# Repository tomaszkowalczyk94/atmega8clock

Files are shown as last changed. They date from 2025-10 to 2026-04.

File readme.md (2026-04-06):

# ATmega8 Digital LED Clock ⏰

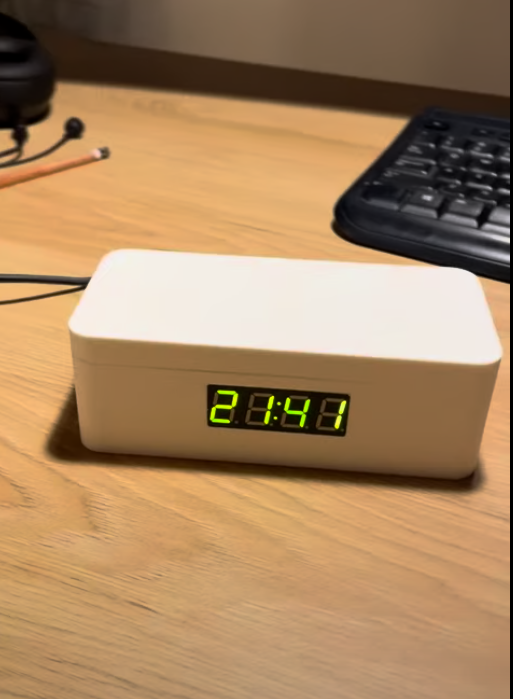
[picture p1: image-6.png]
|  |

A custom-built, DIY digital clock powered by an **ATmega8** microcontroller and a 4-digit 7-segment green LED display. This project involves a custom perfboard circuit, transistor-based display multiplexing, and a fully custom 3D-printed enclosure designed in FreeCAD.

## 🌟 Features
* **Microcontroller:** Atmel ATmega8 
* **Display:** 0.56" 4-Digit 7-Segment LED display with colons/dots (LED4-AF-05643FG-B PBF).
* **Multiplexing:** Utilizes BC547 NPN transistors for switching the common anodes.
* **Custom Enclosure:** 3D printed case and lid, originally modeled in FreeCAD.
* **Programming:** Flashed via a USBAsp programmer using Arduino IDE.

---

## 🛠️ Hardware & Components

* **1x ATmega8** Microcontroller
* **1x LED4-AF-05643FG-B PBF** (4-Digit 7-Segment Display, 0.56", Green, Common Anode)
* **5x BC547 NPN Transistors** (Used to drive the common anodes)
* **Resistors** (For base current limiting on the transistors and segment current limiting)
* **USBAsp Programmer** (For flashing the ATmega8)
* Universal perfboard/stripboard

---

## 🔌 Circuit & Pinout

The display requires multiplexing. The **Common Anodes** are driven by the ATmega8 via BC547 NPN transistors (which conduct when a high signal is applied to the base). The **Cathodes** are connected directly to the ATmega8 digital pins. 

### Anode Connections (via BC547 Transistors)
| Display Pin | ATmega8 Pin (Arduino IDE) | Function |
| :--- | :--- | :--- |
| **14** | Digital Pin 13 | DIGIT 1 |
| **11** | Digital Pin 10 | DIGIT 2 |
| **10** | Digital Pin 9 | DIGIT 3 |
| **7** | Digital Pin 6 | Colon / Dots (UC, LC) |
| **6** | Digital Pin 5 | DIGIT 4 |

### Cathode Connections (Direct to ATmega8)
| Display Pin | ATmega8 Pin (Arduino IDE) | Segment |
| :--- | :--- | :--- |
| **13** | Digital Pin 12 | Segment A |
| **9** | Digital Pin 8 | Segment B |
| **4** | Digital Pin 3 | Segment C |
| **2** | Digital Pin 1 | Segment D |
| **1** | Digital Pin 0 | Segment E |
| **12** | Digital Pin 11 | Segment F |
| **5** | Digital Pin 4 | Segment G |
| **3** | Digital Pin 2 | Dot (DP / OP) |
| **8** | Digital Pin 7 | Colon (UC, LC) |

---

## 📦 3D Printed Enclosure

The repository includes custom 3D models for the clock's housing.
* **`case.FCStd`**: The original FreeCAD project file. Use this if you want to modify the dimensions or design.
* **`case-PartBody.stl`**: The main body of the enclosure, ready for slicing and 3D printing.
* **`case-wieczkoThickness001.stl`**: The back lid/cover for the enclosure.

*Tip: Print with standard PLA/PETG. No special supports are required if oriented face-down.*

---

## 💻 Software & Programming

The code for this project was written in the Arduino IDE and leverages basic multiplexing logic to illuminate the 7-segment display. 

**Flashing the ATmega8:**
1. You will need a **USBAsp** programmer.
2. Install the necessary drivers using [Zadig](https://zadig.akeo.ie/).
3. Connect the USBAsp to the ATmega8 via the ISP headers.
4. In Arduino IDE, select the ATmega8 board, set the programmer to "USBAsp", and click **"Upload Using Programmer"**.

*Helpful resources for programming raw AVR chips:*
* [Majsterkowo: Programming microcontrollers with USBAsp (Polish)](https://majsterkowo.pl/programowanie-mikrokontrolerow-za-pomoca-programatora-usbasp/)
* [YouTube Tutorial](https://www.youtube.com/watch?v=X01Nhq8TeY0&t=58s)

---

## 📸 Gallery

| Circuit Design | 
| :---: 
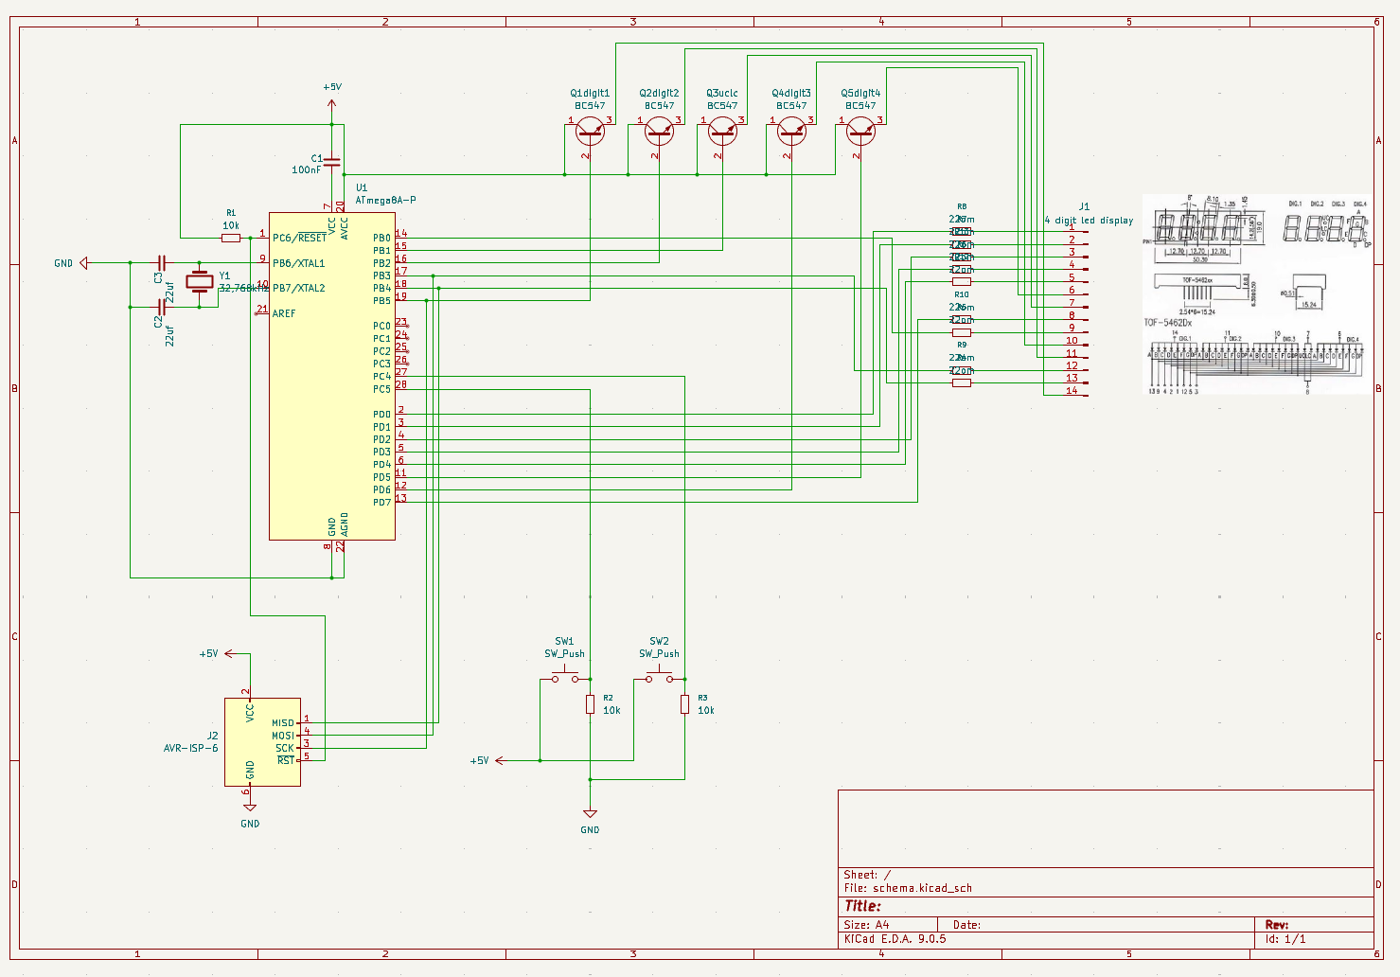
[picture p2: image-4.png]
|  |

| Prototype | 
| :---: 
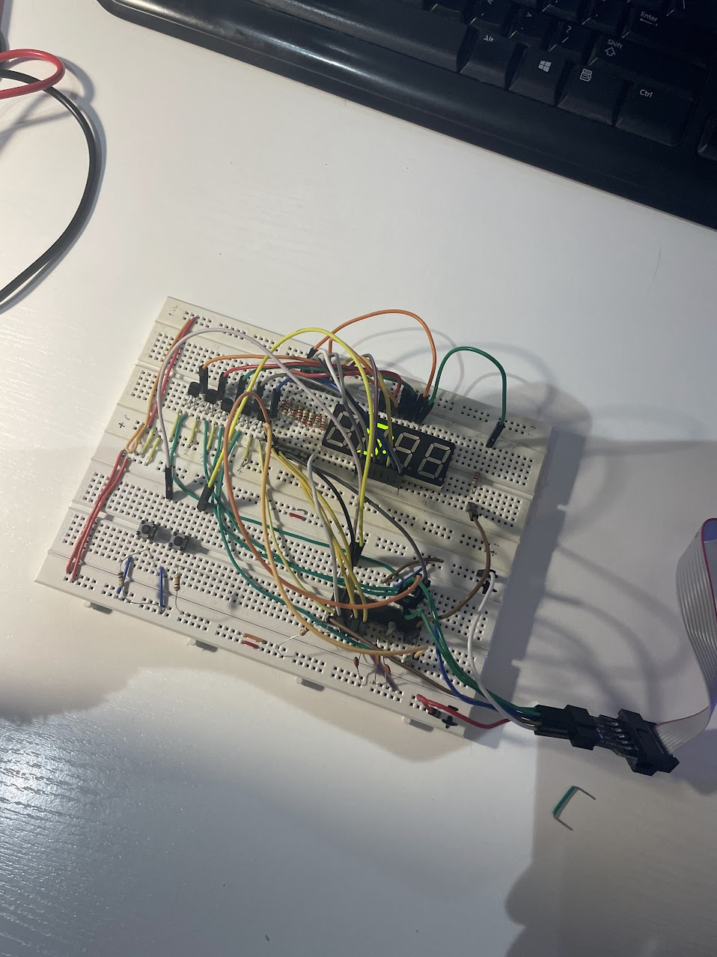
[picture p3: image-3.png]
|  |

| Final electronic board | 
| :---: 
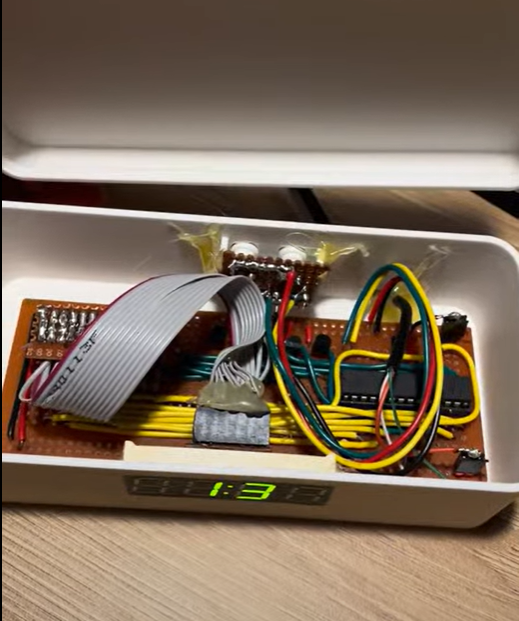
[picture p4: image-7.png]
|  |

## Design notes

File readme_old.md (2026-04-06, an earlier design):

* USBAsp drivers: https://zadig.akeo.ie/
* https://majsterkowo.pl/programowanie-mikrokontrolerow-za-pomoca-programatora-usbasp/
* https://www.youtube.com/watch?v=X01Nhq8TeY0&t=58s
* https://veecad.com/downloads.html







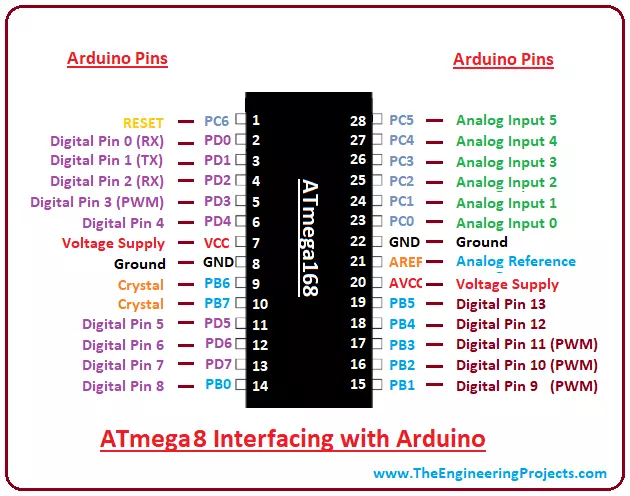
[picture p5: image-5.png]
	
LED4-AF-05643FG-B PBF

Wyświetlacz LED 14,20mm 0,56" cztery cyfry

zielony (570nm) , 4000 ucd (10mA) , wspólna anoda

aktywne wszystkie kropki (przy cyfrach i zegarkowe)

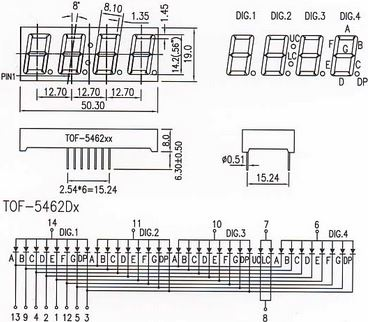
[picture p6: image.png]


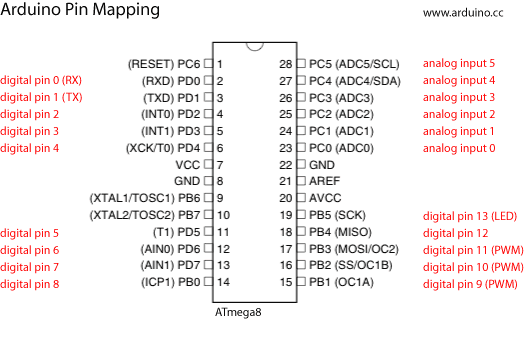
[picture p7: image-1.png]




typ NPN zacznie przewodzić, gdy do bazy przyłożymy napięcie dodatnie względem emitera, czyli przy standardowym podłączeniu na bazę podamy wysoki potencjał (plus z baterii),
typ PNP zacznie przewodzić, gdy do bazy przyłożymy napięcie ujemne względem emitera, czyli przy standardowym podłączeniu na bazę podamy niski potencjał (masę, minus z baterii).

bc547 b (NPN)
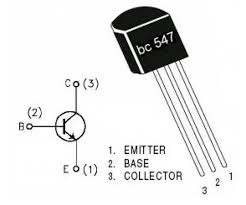
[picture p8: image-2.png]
 

 połączenie do atmega8:
 nr pinu wyświetlacza odpowiada pinowi cyfrowemu arduino

Podłączenie anod (+) przez bc547
 displey - atmega
14 - digital pin 13 (DIGIT 1)
11 - digital pin 10 (DIGIT 2)
10 - digital pin 9 (DIGIT 3)
7 - digital pin 6 (UC, LC)
6 - digital pin 5 (DIGIT 4)

podłączenie katod (-) bezpośrednio do atmegi
13 - digital pin 12 (segment A)
9 - digital pin 8 (segment B)
4 - digital pin 3 (segment C)
2 - digital pin 1 (segment D)
1 - digital pin 0 (segment E)
12 - digital pin 11 (segment F)
5 - digital pin 4 (segment G)
3 - digital pin 2 (segment OP)
8 - digital pin 7 (segment UC, LC)

## chatgpt prompt:

napisz mi kod do arduino studio. Posiadam atmega 8 i wyświetlacz 4 segmentowy z kropkami przy cyfrach i dwukropkiem między drugą i trzecią cyfrą. 

Chce zrobić zegarek z wyświetlaczem 7 segmentowym. Oto podłączenie pinów:

 połączenie do atmega8:
 nr pinu wyświetlacza odpowiada pinowi cyfrowemu arduino

Podłączenie anod (-) przez bc547
 displey - atmega
14 - digital pin 13 (DIGIT 1)
11 - digital pin 10 (DIGIT 2)
10 - digital pin 9 (DIGIT 3)
7 - digital pin 6 (UC, LC)
6 - digital pin 5 (DIGIT 4)

podłączenie katod (-) bezpośrednio do atmegi
13 - digital pin 12 (segment A)
9 - digital pin 8 (segment B)
4 - digital pin 3 (segment C)
2 - digital pin 1 (segment D)
1 - digital pin 0 (segment E)
12 - digital pin 11 (segment F)
5 - digital pin 4 (segment G)
3 - digital pin 2 (segment OP)
8 - digital pin 7 (segment UC, LC)

każda cyfra ma wspólną anode, i różne katody.

Stan niski na katodzie włącza wyświetlanie

Chce aby co sekunde migał dwukropem między cyfrą 3 a 2. Są to piny nazwane UC i LC. (anoda ditial pin 6 na atmega, katoda digital pin 7 na atmega)
Komentarze mają być po angielsku

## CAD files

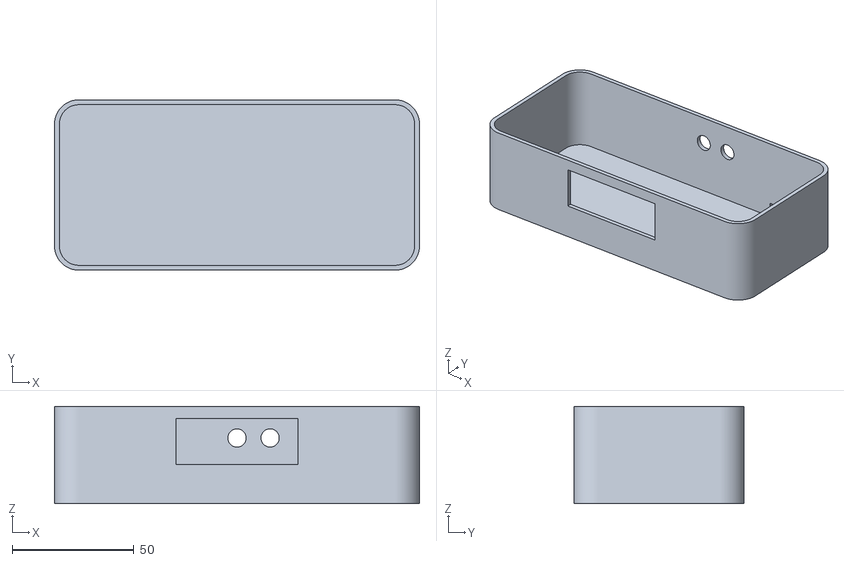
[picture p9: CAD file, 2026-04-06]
case-PartBody.stl
150.0 x 70.0 x 40.0

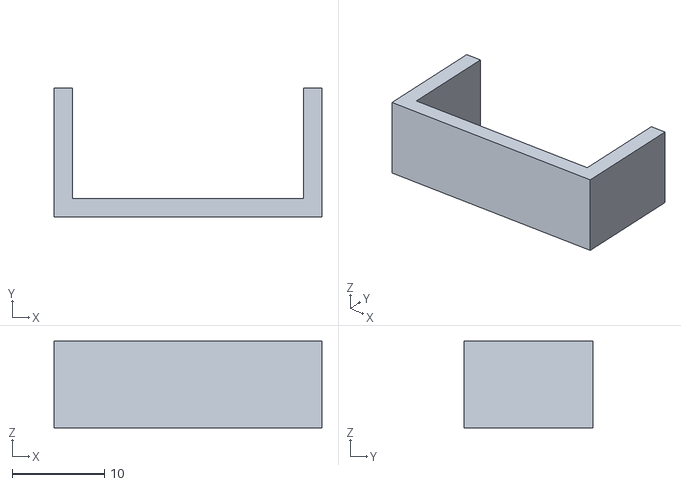
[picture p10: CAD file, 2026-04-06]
button holder.stl
29.0 x 14.0 x 9.39

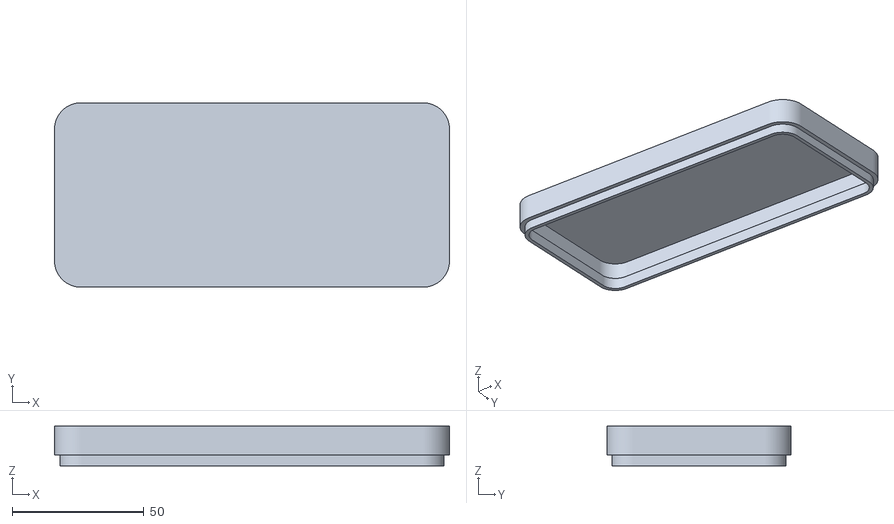
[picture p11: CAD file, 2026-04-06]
case-wieczkoThickness001.stl
150.0 x 70.0 x 15.0

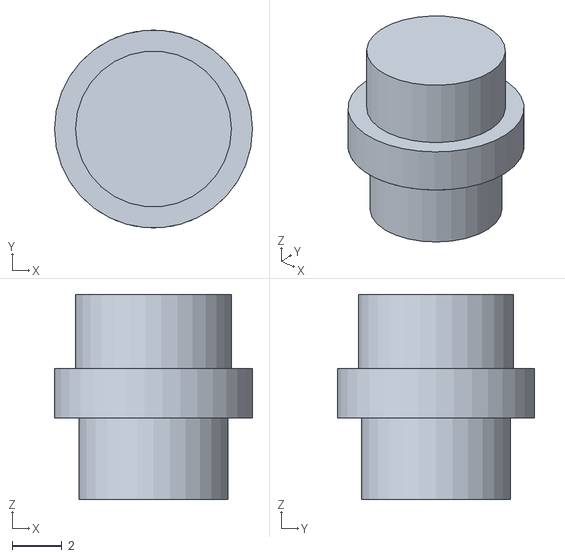
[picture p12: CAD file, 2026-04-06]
button.stl
8.00 x 8.00 x 8.30

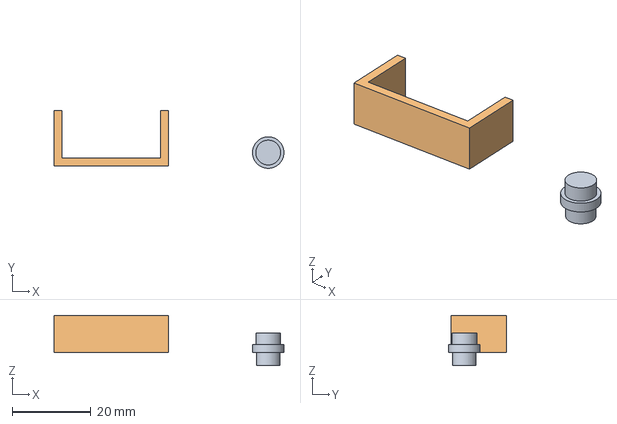
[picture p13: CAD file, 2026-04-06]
case.FCStd
58.3 x 14.6 x 12.7 mm
buttons

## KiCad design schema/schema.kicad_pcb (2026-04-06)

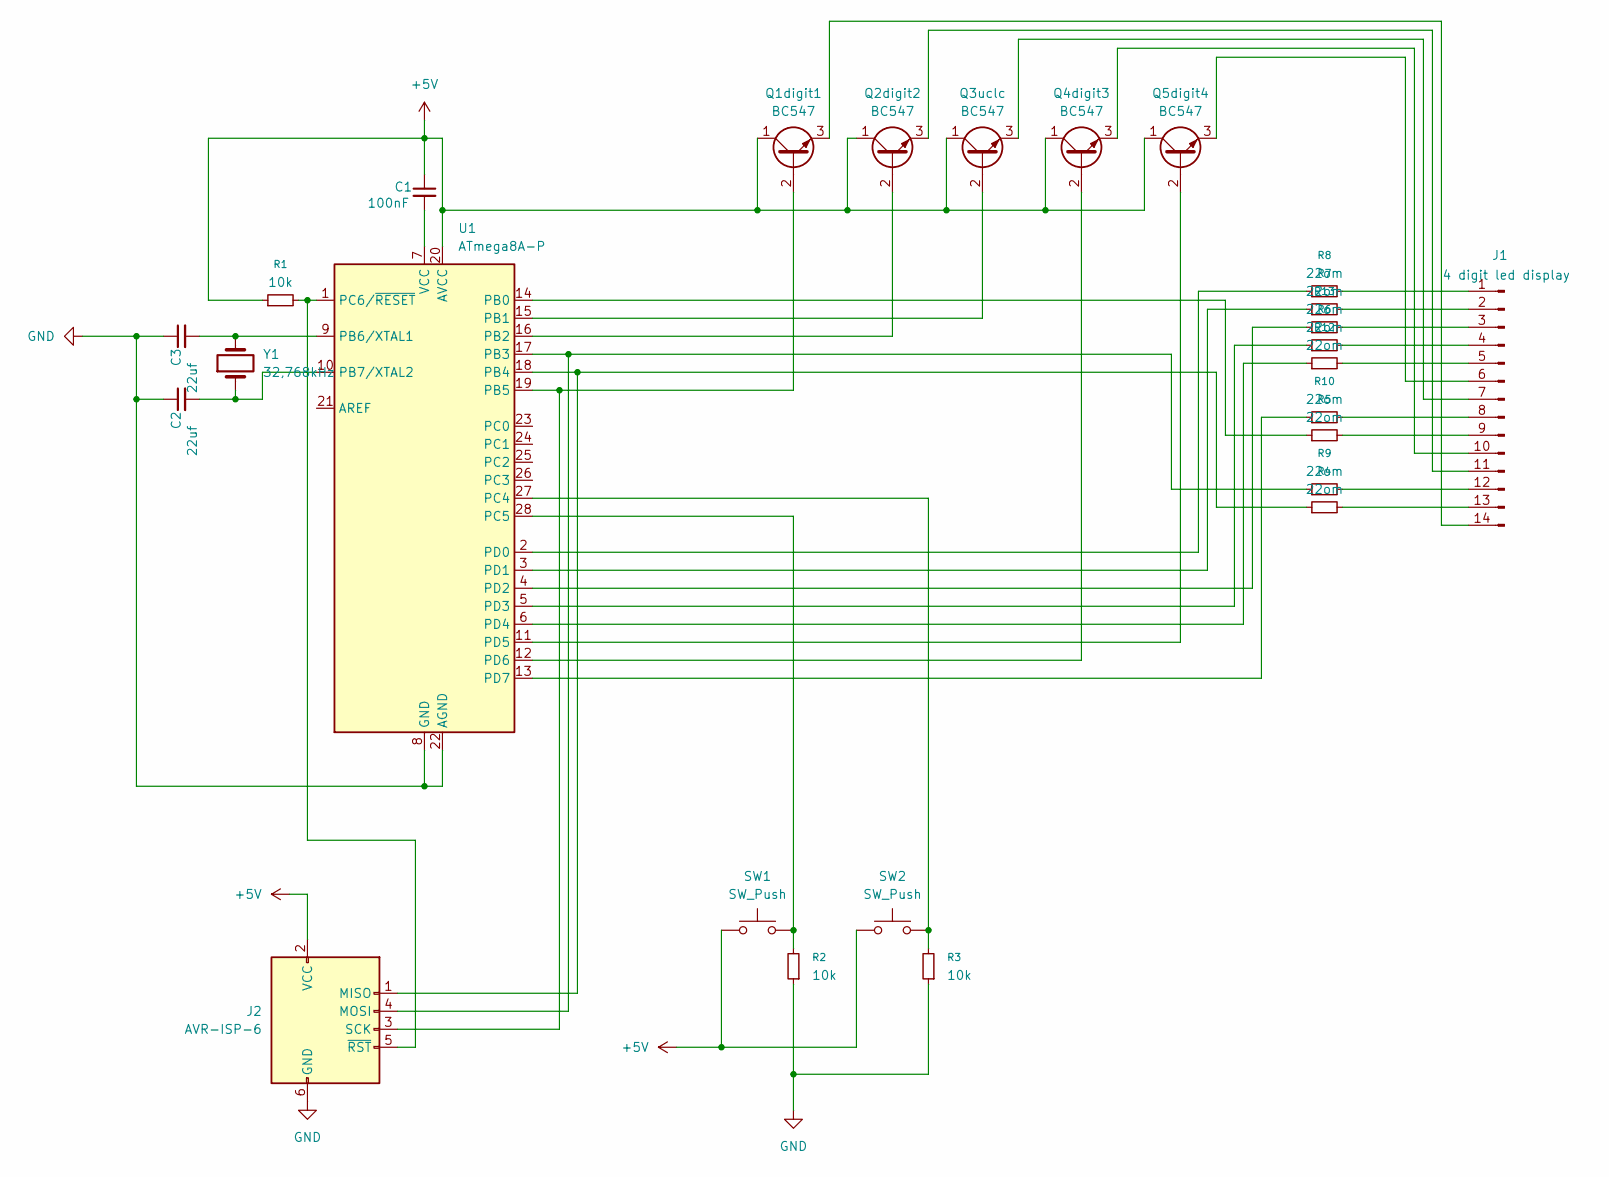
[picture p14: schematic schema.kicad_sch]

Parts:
C1: 100nF
C2, C3: 22uf
J1: 4 digit led display; Hirose_DF13-14P-1.25DSA_1x14_P1.25mm_Vertical
J2: AVR-ISP-6
Q1digit1, Q2digit2, Q3uclc, Q4digit3, Q5digit4: BC547; TO-92_Inline
R1, R2, R3: 10k
R4, R5, R6, R7, R8, R9, R10, R12, R13: 22om
SW1, SW2: SW_Push
U1: ATmega8A-P; DIP-28_W7.62mm
Y1: 32,768kHz

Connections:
+5V: C1.1, J2.2 (VCC), Q1digit1.1 (C), Q2digit2.1 (C), Q3uclc.1 (C), Q4digit3.1 (C), Q5digit4.1 (C), R1.1, SW1.1, SW2.1, U1.20 (AVCC); also elsewhere on the board
GND: C2.1, C3.1, J2.6 (GND), R2.1, R3.1, U1.8 (GND), U1.22 (AGND)
unnamed: J1.1, R8.2
unnamed: J1.2, R7.2
unnamed: J1.3, R13.2
unnamed: J1.4, R6.2
unnamed: J1.5, R12.2
unnamed: J1.6, Q5digit4.3 (E)
unnamed 8: J1.7, Q3uclc.3 (E); also elsewhere on the board
unnamed: J1.8, R10.2
unnamed: J1.9, R5.2
unnamed: J1.10, Q4digit3.3 (E)
unnamed: J1.11, Q2digit2.3 (E)
unnamed: J1.12, R9.2
unnamed: J1.13, R4.2
unnamed: J1.14, Q1digit1.3 (E)
unnamed: J2.1 (MISO), R4.1, U1.18 (PB4)
unnamed: J2.4 (MOSI), R9.1, U1.17 (PB3)
unnamed: J2.3 (SCK), Q1digit1.2 (B), U1.19 (PB5)
unnamed: J2.5 (~RST), R1.2, U1.1 (PC6/~RESET)
unnamed: Q2digit2.2 (B), U1.16 (PB2)
unnamed 21: Q3uclc.2 (B), U1.15 (PB1); also elsewhere on the board
unnamed: Q4digit3.2 (B), U1.12 (PD6)
unnamed: Q5digit4.2 (B), U1.11 (PD5)
unnamed: R5.1, U1.14 (PB0)
unnamed: C3.2, U1.9 (PB6/XTAL1), Y1.2
unnamed: C2.2, U1.10 (PB7/XTAL2), Y1.1
unnamed: R3.2, SW2.2, U1.27 (PC4)
unnamed: R2.2, SW1.2, U1.28 (PC5)
unnamed: R8.1, U1.2 (PD0)
unnamed: R7.1, U1.3 (PD1)
unnamed: R13.1, U1.4 (PD2)
unnamed: R6.1, U1.5 (PD3)
unnamed: R12.1, U1.6 (PD4)
unnamed: R10.1, U1.13 (PD7)
unnamed: C1.2, U1.7 (VCC)

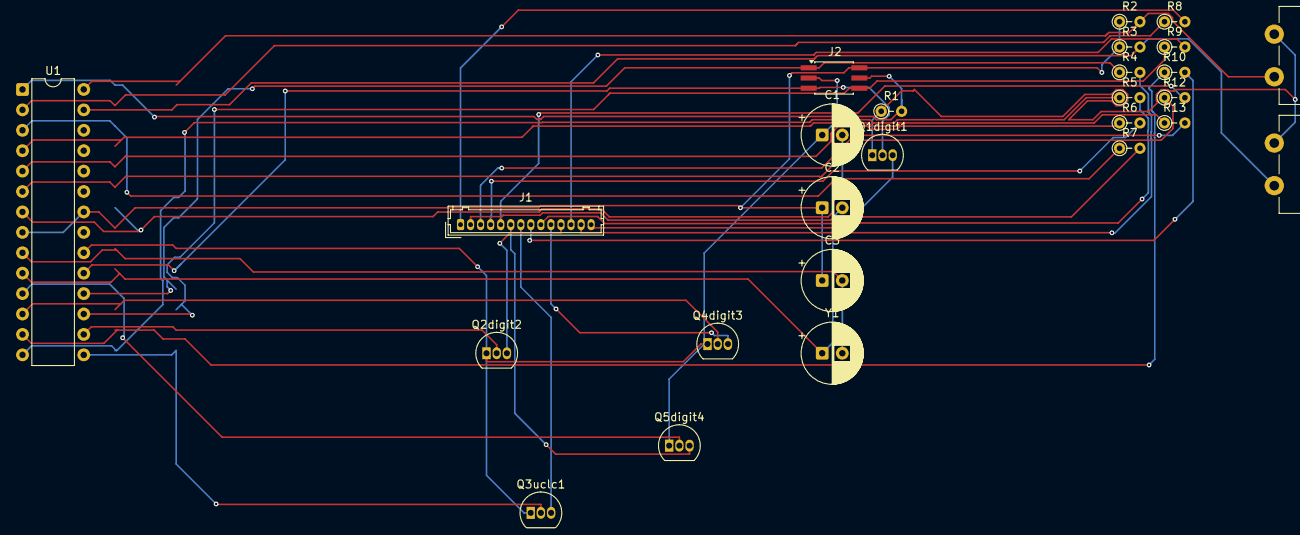
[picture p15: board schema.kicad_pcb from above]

Board: 2 copper layers, 26 parts (0 on the bottom side), 36 nets.

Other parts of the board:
Q3uclc1: BC547; TO-92_Inline

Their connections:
+5V: Q3uclc1.1 (C); also elsewhere on the board
unnamed 8: Q3uclc1.3 (E); also elsewhere on the board
unnamed 21: Q3uclc1.2 (B); also elsewhere on the board

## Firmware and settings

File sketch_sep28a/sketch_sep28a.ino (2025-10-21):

/*
  4-digit 7-segment clock for ATmega8
  Common anode display controlled through BC547 transistors
  Active LOW segments (LOW = ON)
  Active HIGH digit select (HIGH = digit ON)
  Colon (:) blinks every second between digit 2 and digit 3
  Comments in English
*/

#include <Arduino.h>

const int button1 = A5;   // pin przycisku
const int button2 = A4;
const unsigned long debounceDelay = 50; // czas antydrganiowy (ms)

int button1State;             // aktualny stan
int button2State;   
int lastButton1State = LOW;   // poprzedni stan
int lastButton2State = LOW;   
unsigned long lastDebounceTime1 = 0; // ostatni czas zmiany
unsigned long lastDebounceTime2 = 0; // ostatni czas zmiany

const int delayBetweenDigits = 2; 

// ----- Segment pin definitions -----
const int segA = 12; // segment A
const int segB = 8;  // segment B
const int segC = 3;  // segment C
const int segD = 1;  // segment D
const int segE = 0;  // segment E
const int segF = 11; // segment F
const int segG = 4;  // segment G
const int segDP = 2; // decimal point
const int segUC = 7; // colon cathode (UC/LC)

// ----- Digit control pins (through BC547 transistors) -----
const int digit1 = 13; // DIGIT 1
const int digit2 = 10; // DIGIT 2
const int digit3 = 9;  // DIGIT 3
const int digitUC_LC = 6; // Colon anode
const int digit4 = 5;  // DIGIT 4

// ----- Time variables -----
int hours = 0;
int minutes = 0;
int seconds = 0;

unsigned long previousMillis = 0;
bool colonState = true; // Blinking colon state
bool dotDigit1 = false;
bool dotDigit2 = false;
bool dotDigit3 = false;
bool dotDigit4 = false;

// ----- Segment patterns for digits 0–9 (active LOW) -----
const byte digitPatterns[10][7] = {
  {0,0,0,0,0,0,1}, // 0
  {1,0,0,1,1,1,1}, // 1
  {0,0,1,0,0,1,0}, // 2
  {0,0,0,0,1,1,0}, // 3
  {1,0,0,1,1,0,0}, // 4
  {0,1,0,0,1,0,0}, // 5
  {0,1,0,0,0,0,0}, // 6
  {0,0,0,1,1,1,1}, // 7
  {0,0,0,0,0,0,0}, // 8
  {0,0,0,0,1,0,0}  // 9
};

// ----- Setup -----
void setup() {
  pinMode(button1, INPUT);
  pinMode(button2, INPUT);

  // Segment pins
  pinMode(segA, OUTPUT);
  pinMode(segB, OUTPUT);
  pinMode(segC, OUTPUT);
  pinMode(segD, OUTPUT);
  pinMode(segE, OUTPUT);
  pinMode(segF, OUTPUT);
  pinMode(segG, OUTPUT);
  pinMode(segDP, OUTPUT);
  pinMode(segUC, OUTPUT);

  // Digit pins
  pinMode(digit1, OUTPUT);
  pinMode(digit2, OUTPUT);
  pinMode(digit3, OUTPUT);
  pinMode(digitUC_LC, OUTPUT);
  pinMode(digit4, OUTPUT);

  allDigitsOff();

  timer2_init();
}

// ----- Helper functions -----

// Turn off all digits
void allDigitsOff() {
  digitalWrite(digit1, LOW);
  digitalWrite(digit2, LOW);
  digitalWrite(digit3, LOW);
  digitalWrite(digitUC_LC, LOW);
  digitalWrite(digit4, LOW);
}

// Display a digit (0–9)
void showNumber(int num, bool dot) {
  for (int i = 0; i < 7; i++) {
    digitalWrite(segmentPin(i), digitPatterns[num][i]);
  }
  digitalWrite(segDP, !dot); // Decimal point off
}

// Return correct segment pin by index
int segmentPin(int index) {
  const int pins[7] = {segA, segB, segC, segD, segE, segF, segG};
  return pins[index];
}

// Show one number on a selected digit
void showDigit(int number, bool dot,  int digitPin) {
  allDigitsOff();         // Disable all digits
  showNumber(number, dot);     // Set segments
  digitalWrite(digitPin, HIGH); // Enable digit (active HIGH)
}

// Display the time HH:MM with blinking colon
void displayTime() {
  int d1 = hours / 10;
  int d2 = hours % 10;
  int d3 = minutes / 10;
  int d4 = minutes % 10;
  
  showDigit(d1, dotDigit1, digit1);
  delay(delayBetweenDigits);
  
  showDigit(d2, dotDigit2, digit2);
  delay(delayBetweenDigits);
  

  // Colon blink control
  
  if (colonState) {
    allDigitsOff();
    digitalWrite(segUC, LOW);     // Colon ON (active LOW)
    digitalWrite(digitUC_LC, HIGH);
  } else {
    allDigitsOff();
    digitalWrite(digitUC_LC, LOW);
    digitalWrite(segUC, HIGH);    // Turn colon OFF after brief flash
  }
  delay(delayBetweenDigits);

  showDigit(d3, dotDigit3, digit3);
  delay(delayBetweenDigits);

  showDigit(d4, dotDigit4, digit4);
  delay(delayBetweenDigits);
}


// ----- Time update -----
void updateTime() {
    seconds++;

    // Blink colon every second
    colonState = !colonState;

    if (seconds >= 60) {
      seconds = 0;
      minutes++;
      if (minutes >= 60) {
        minutes = 0;
        hours++;
        if (hours >= 24) hours = 0;
      }
    }
  
}


// ----- Main loop -----
void loop() {


  handleButton1();
  handleButton2();


  displayTime();
  
}



void handleButton1() {
  
  int reading = digitalRead(button1);
  // jeśli stan się zmienił → zresetuj timer
  if (reading != lastButton1State) {
    lastDebounceTime1 = millis();
  }

  // jeśli minął czas stabilizacji
  if ((millis() - lastDebounceTime1) > debounceDelay) {
    // jeśli stan jest inny niż ostatnio potwierdzony
    if (reading != button1State) {
      button1State = reading;

      if (button1State == HIGH) {
        button1Pressed();
      }
    }
  }

  lastButton1State = reading;
}

void handleButton2() {
  
  int reading = digitalRead(button2);
  // jeśli stan się zmienił → zresetuj timer
  if (reading != lastButton2State) {
    lastDebounceTime2 = millis();
  }

  // jeśli minął czas stabilizacji
  if ((millis() - lastDebounceTime2) > debounceDelay) {
    // jeśli stan jest inny niż ostatnio potwierdzony
    if (reading != button2State) {
      button2State = reading;

      if (button2State == HIGH) {
        button2Pressed();
      }
    }
  }

  lastButton2State = reading;
}

void button1Pressed() {
  if(dotDigit2) {
    dotDigit2 = false;
    dotDigit4 = true;
    return;
  }
  if(dotDigit4) {
    dotDigit4 = false;
    return;
  }
  dotDigit2 = true;
}

void button2Pressed() {
  if(dotDigit2) {
    hours++;
    if (hours >= 24) hours = 0;
  }

  if(dotDigit4) {
    minutes++;
   if (minutes >= 60) minutes = 0;
  }
}

void timer2_init(void) {
    // Włącz tryb asynchroniczny
    ASSR = (1 << AS2);
    
    // Ustaw preskaler 128
    TCCR2 = (1 << CS22) | (1 << CS20);
    
    // Zeruj licznik
    TCNT2 = 0;

    // Poczekaj na synchronizację
    while (ASSR & ((1 << TCN2UB) | (1 << TCR2UB) | (1 << OCR2UB)));

    // Włącz przerwanie od overflow
    TIMSK |= (1 << TOIE2);
}

ISR(TIMER2_OVF_vect) {
    updateTime();
}
